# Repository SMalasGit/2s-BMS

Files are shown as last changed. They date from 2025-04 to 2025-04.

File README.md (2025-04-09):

This chip is rated for 1-2s (cell) operation with lithium ion or lithium polymer batteries. This BMS config is set up for a 5 amp charging current at an 8.4 voltage running, which is supplied via the USB-C port of the BMS. This BMS has built in trip current of 35 amps, and a physical fuse onboard for currents exceeding 25 amps. This helps ensure the safety of the device and battery packBMSB
BMSF

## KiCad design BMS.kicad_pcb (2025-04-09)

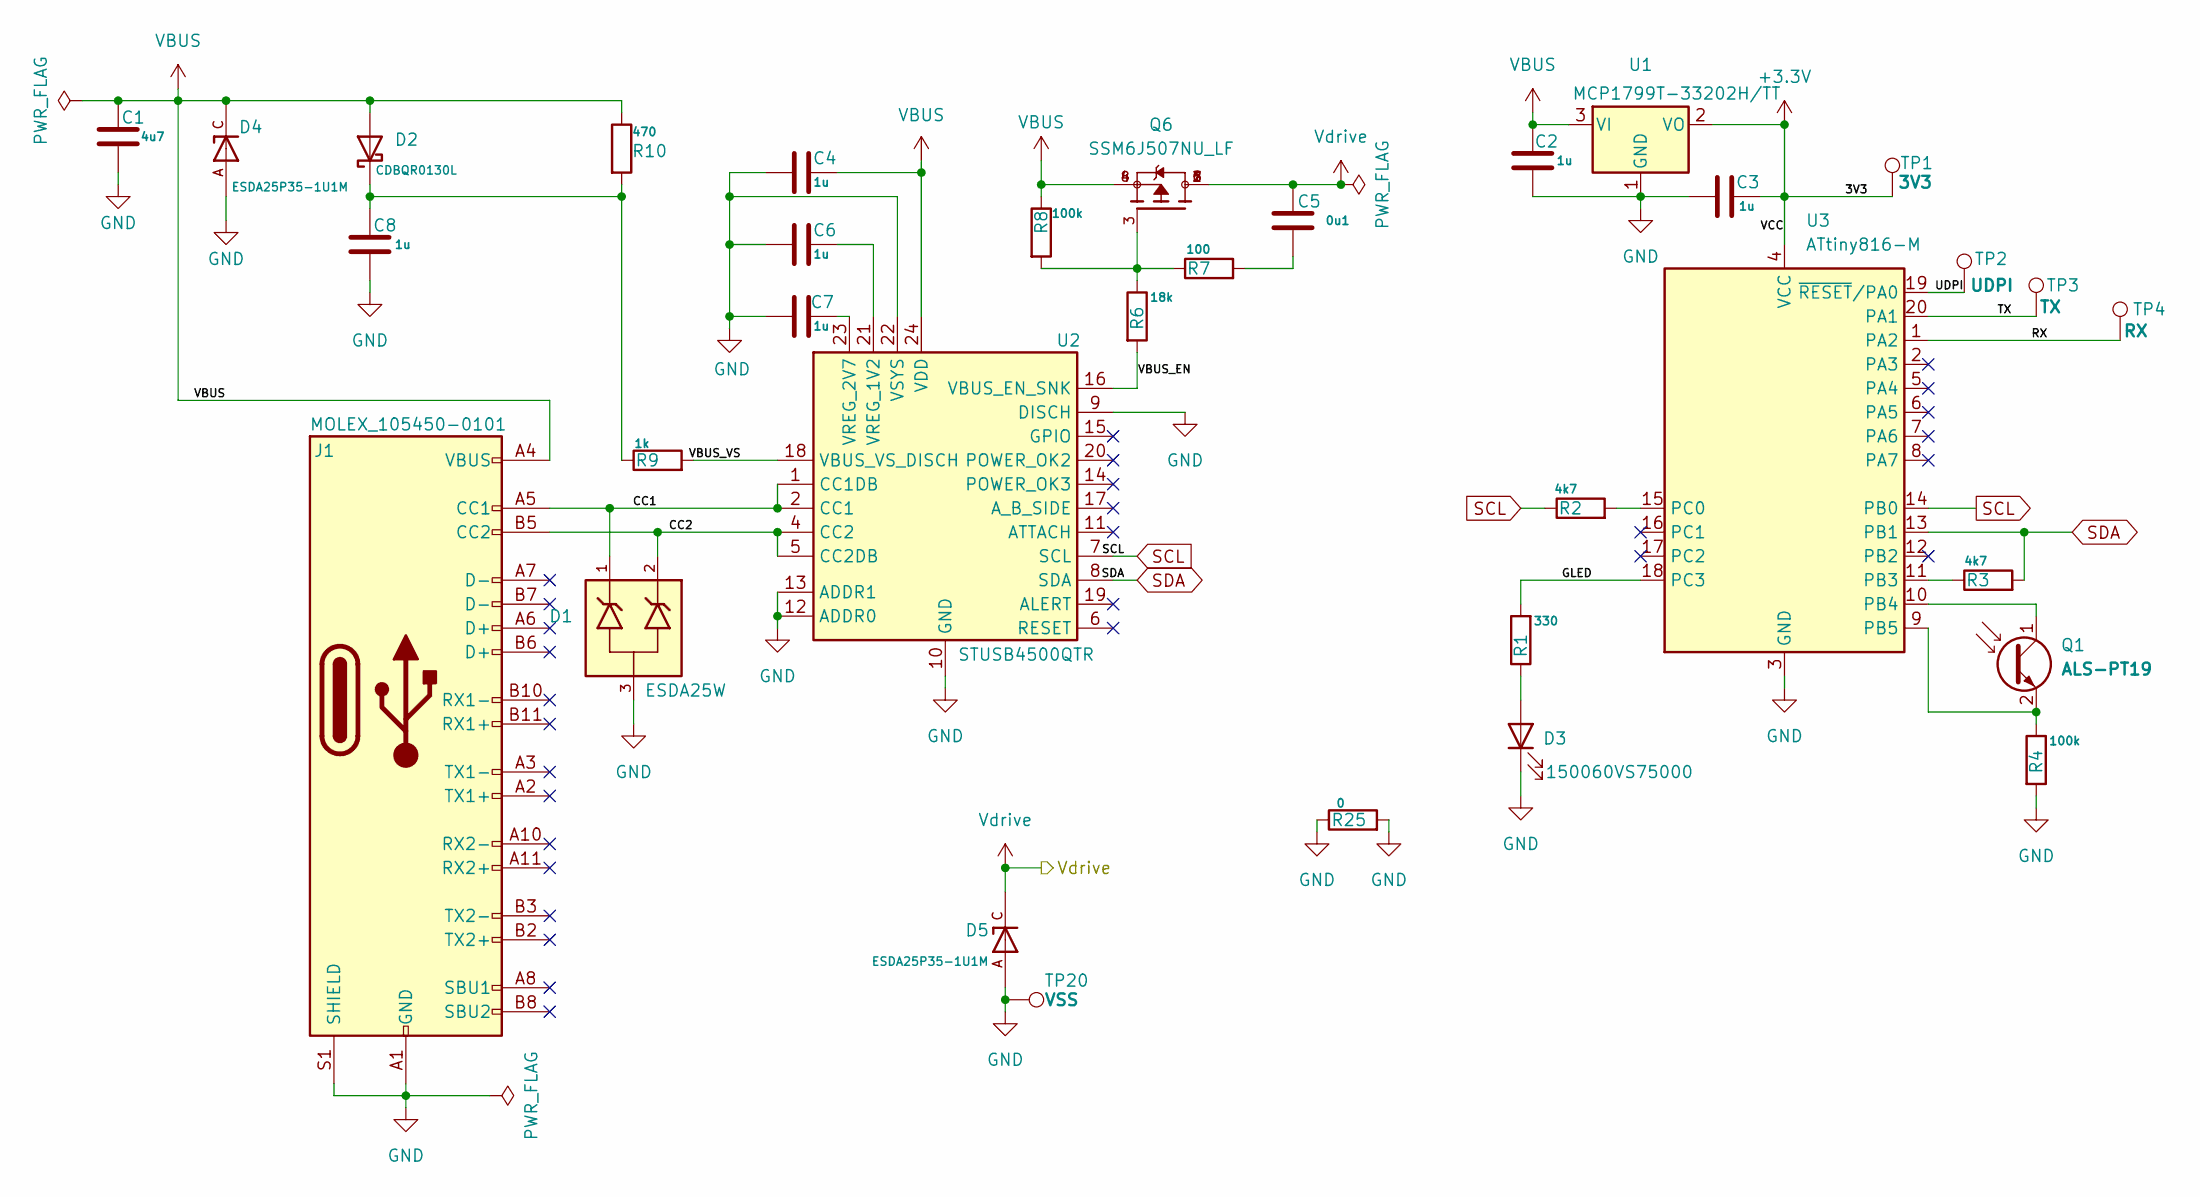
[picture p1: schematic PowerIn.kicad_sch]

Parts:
C1: 4u7; C_0603_1608Metric
C2, C3, C4, C6, C7, C8: 1u; C_0402_1005Metric
C5: 0u1; C_0402_1005Metric
D1: ESDA25W; SOT65P210X110-3N; PARTREV 2
D2: CDBQR0130L; D_0402_1005Metric
D3: 150060VS75000; LED_0603_1608Metric
D4, D5: ESDA25P35-1U1M; TVS_ESDA25P35-1U1M; PARTREV 2
J1: MOLEX_105450-0101; USB_C_Receptacle_Molex_105450-0101
Q1: ALS-PT19; LED_0603_1608Metric
Q6: SSM6J507NU_LF; TRANS_SSM6J507NU_LF; PARTREV 2.0
R1: 330; R_0603_1608Metric
R2, R3: 4k7; R_0402_1005Metric
R4, R8: 100k; R_0402_1005Metric
R6: 18k; R_0402_1005Metric
R7: 100; R_0402_1005Metric
R9: 1k; R_0402_1005Metric
R10: 470; R_0402_1005Metric
R25: 0; R_0201_0603Metric
TP1: 3V3; test
TP2: UDPI; test
TP3: TX; test
TP4: RX; test
TP20: VSS; PinHeader_1x01_P1.00mm_Vertical
U1: MCP1799T-33202H/TT; SOT-23
U2: STUSB4500QTR; QFN-24-1EP_4x4mm_P0.5mm_EP2.7x2.7mm
U3: ATtiny816-M; VQFN-20-1EP_3x3mm_P0.4mm_EP1.7x1.7mm

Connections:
+3.3V: C3.2, TP1.1, U1.2 (VO), U3.4 (VCC)
/PowerIn/CC1: D1.1, J1.A5 (CC1), U2.1 (CC1DB), U2.2 (CC1)
/PowerIn/CC2: D1.2, J1.B5 (CC2), U2.4 (CC2), U2.5 (CC2DB)
/PowerIn/GLED: R1.2, U3.18 (PC3)
/PowerIn/RX: TP4.1, U3.1 (PA2)
/PowerIn/TX: TP3.1, U3.20 (PA1)
/PowerIn/UDPI: TP2.1, U3.19 (~RESET/PA0)
/PowerIn/VBUS_EN: R6.2, U2.16 (VBUS_EN_SNK)
/PowerIn/VBUS_VS: R9.2, U2.18 (VBUS_VS_DISCH)
GND: C1.2, C2.1, C3.1, C4.1, C6.1, C7.1, C8.2, D1.3, D3.1 (K), D4.A, D5.A, J1.A1 (GND), J1.A12 (GND), J1.B1 (GND), J1.B12 (GND), J1.S1 (SHIELD), R4.2, R25.1, R25.2, TP20.1, U1.1 (GND), U2.9 (DISCH), U2.10 (GND), U2.12 (ADDR0), U2.13 (ADDR1), U2.22 (VSYS), U2.25 (GND), U3.3 (GND), U3.21 (GND); also elsewhere on the board
unnamed: C5.1, R7.2
unnamed: C8.1, D2.1 (K), R9.1, R10.2
unnamed: D3.2 (A), R1.1
unnamed: Q1.1 (C), U3.10 (PB4)
unnamed: Q1.2 (E), R4.1, U3.9 (PB5)
unnamed: Q6.3, R6.1, R7.1, R8.2
unnamed: C6.2, U2.21 (VREG_1V2)
unnamed: C7.2, U2.23 (VREG_2V7)
unnamed: R3.1, U3.11 (PB3)
unnamed: R2.2, U3.15 (PC0)
SCL: R2.1, U2.7 (SCL), U3.14 (PB0)
SDA: R3.2, U2.8 (SDA), U3.13 (PB1)
VBUS: C1.1, C2.2, C4.2, D2.2 (A), D4.C, J1.A4 (VBUS), J1.A9 (VBUS), J1.B4 (VBUS), J1.B9 (VBUS), Q6.4, Q6.8, R8.1, R10.1, U1.3 (VI), U2.24 (VDD)
Vdrive: C5.2, D5.C, Q6.1, Q6.2, Q6.5, Q6.6, Q6.7; also elsewhere on the board

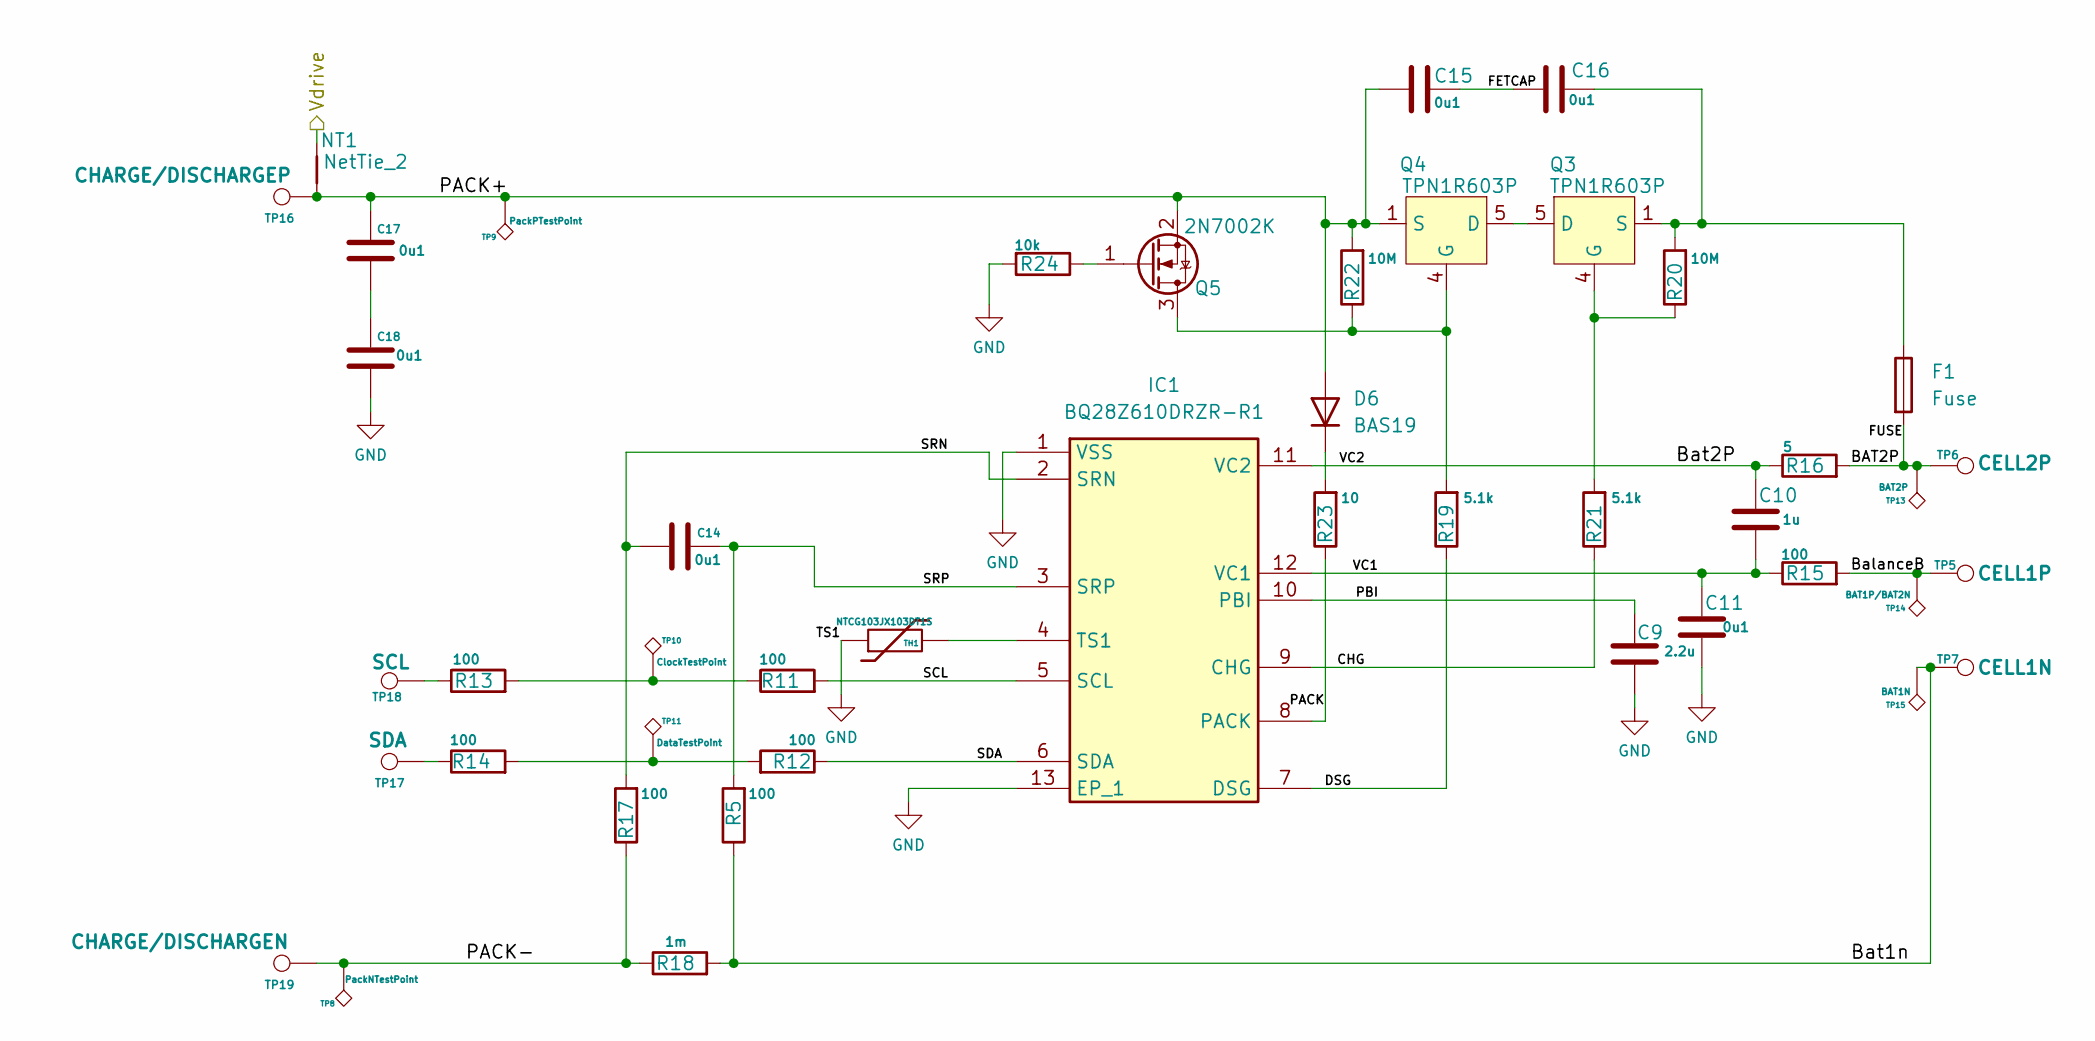
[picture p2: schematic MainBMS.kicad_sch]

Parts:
C9: 2.2u; C_0402_1005Metric
C10: 1u; C_0402_1005Metric
C11, C14, C15, C16, C17, C18: 0u1; C_0402_1005Metric
D6: BAS19; SOT-23
F1: Fuse; Fuse_1206_3216Metric
IC1: BQ28Z610DRZR-R1; IC_BQ27441DRZR-G1A; Mouser Part Number 595-BQ28Z610DRZR-R1
NT1: NetTie_2; NetTie-2_SMD_Pad0.5mm
Q3, Q4: TPN1R603P; TPN1R603PLL1Q
Q5: 2N7002K; SOT-23
R5, R11, R12, R13, R14, R15, R17: 100; R_0402_1005Metric
R16: 5; R_0402_1005Metric
R18: 1m; R_2010_5025Metric
R19, R21: 5.1k; R_0402_1005Metric
R20, R22: 10M; R_0603_1608Metric
R23: 10; R_0402_1005Metric
R24: 10k; R_0402_1005Metric
TH1: NTCG103JX103DT1S; R_0402_1005Metric
TP5: CELL1P; TestPoint_Pad_D1.5mm
TP6: CELL2P; TestPoint_Pad_D2.0mm
TP7: CELL1N; TestPoint_Pad_D2.0mm
TP8: PackNTestPoint; test
TP9: PackPTestPoint; test
TP10: ClockTestPoint; test
TP11: DataTestPoint; test
TP13: BAT2P; test
TP14: BAT1P/BAT2N; test
TP15: BAT1N; test
TP16: CHARGE/DISCHARGEP; TestPoint_Pad_D2.0mm
TP17: SDA; PinHeader_1x01_P1.00mm_Vertical
TP18: SCL; PinHeader_1x01_P1.00mm_Vertical
TP19: CHARGE/DISCHARGEN; TestPoint_Pad_D2.0mm

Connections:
/MainBMS/BAT2P: F1.2, R16.2, TP6.1, TP13.1
/MainBMS/BalanceB: R15.2, TP5.1, TP14.1
/MainBMS/Bat1n: R5.1, R18.2, TP7.1, TP15.1
/MainBMS/Bat2P: C10.2, IC1.11 (VC2), R16.1
/MainBMS/CHG: IC1.9 (CHG), R21.1
/MainBMS/DSG: IC1.7 (DSG), R19.1
/MainBMS/FETCAP: C15.1, C16.2
/MainBMS/PACK: IC1.8 (PACK), R23.1
/MainBMS/PACK+: C15.2, C17.1, D6.1 (A), NT1.1, Q4.1 (S), Q4.2 (S), Q4.3 (S), Q5.2 (S), R22.2, TP9.1, TP16.1
/MainBMS/PACK-: R17.1, R18.1, TP8.1, TP19.1
/MainBMS/PBI: C9.2, IC1.10 (PBI)
/MainBMS/SCL: IC1.5 (SCL), R11.2
/MainBMS/SDA: IC1.6 (SDA), R12.1
/MainBMS/SRN: C14.2, IC1.2 (SRN), R17.2
/MainBMS/SRP: C14.1, IC1.3 (SRP), R5.2
/MainBMS/VC1: C10.1, C11.2, IC1.12 (VC1), R15.1
GND: C9.1, C11.1, C18.2, IC1.1 (VSS), IC1.13 (EP_1), IC1.14 (EP_2), IC1.15 (EP_3), R24.2, TH1.1; also elsewhere on the board
unnamed: C16.1, F1.1, Q3.1 (S), Q3.2 (S), Q3.3 (S), R20.2
unnamed: C17.2, C18.1
unnamed 29: R11.1, R13.2, TP10.1; also elsewhere on the board
unnamed 30: R12.2, R14.2, TP11.1; also elsewhere on the board
unnamed: D6.3 (K), R23.2
unnamed: IC1.4 (TS1), TH1.2
unnamed: Q3.5 (D), Q3.6 (D), Q3.7 (D), Q3.8 (D), Q3.9 (D), Q4.5 (D), Q4.6 (D), Q4.7 (D), Q4.8 (D), Q4.9 (D)
unnamed: Q3.4 (G), R20.1, R21.2
unnamed: Q4.4 (G), Q5.3 (D), R19.2, R22.1
unnamed: Q5.1 (G), R24.1
unnamed: R13.1, TP18.1
unnamed: R14.1, TP17.1
Vdrive: NT1.2; also elsewhere on the board

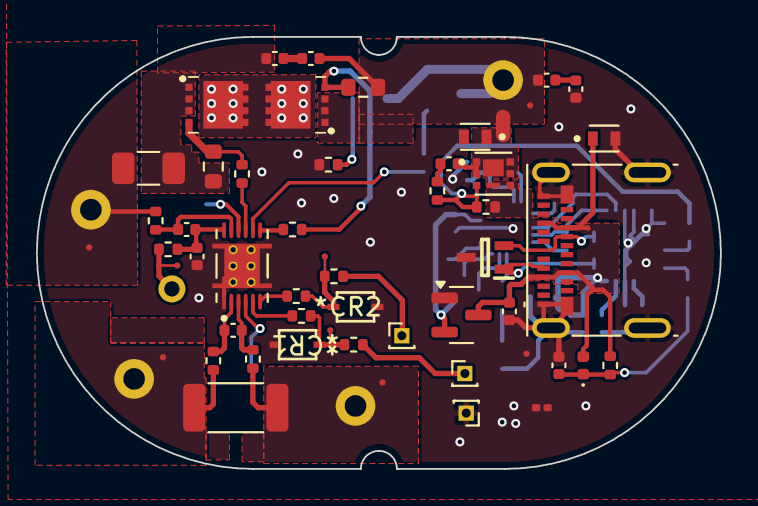
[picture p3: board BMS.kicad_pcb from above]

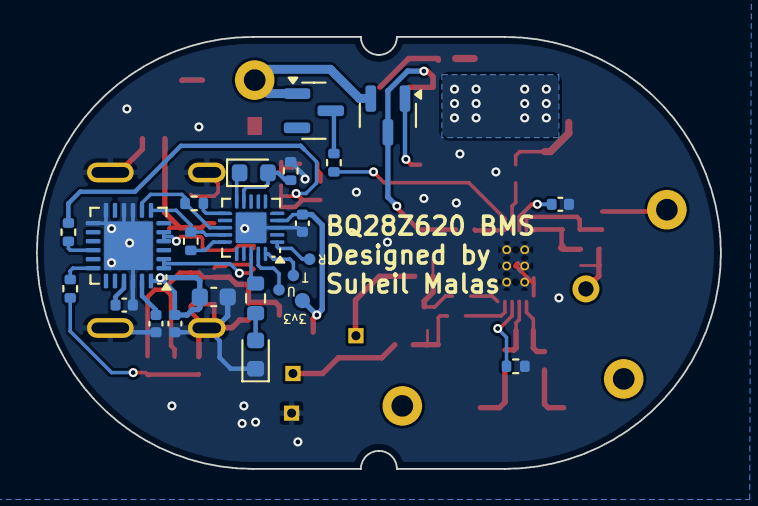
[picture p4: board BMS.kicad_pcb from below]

Board: 2 copper layers, 38.0 x 24.0 mm, 82 parts (24 on the bottom side), 52 nets.

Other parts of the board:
CR1, CR2: MM3Z5V6C; ZDO_MM3Z5V6C_OSI
TP12: GndATestPoint; test

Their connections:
GND: CR1.2, CR2.2, TP12.1; also elsewhere on the board
unnamed 29: CR1.1; also elsewhere on the board
unnamed 30: CR2.1; also elsewhere on the board
